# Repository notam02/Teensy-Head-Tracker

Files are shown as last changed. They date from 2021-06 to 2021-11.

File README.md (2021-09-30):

# Teensy Head Tracker
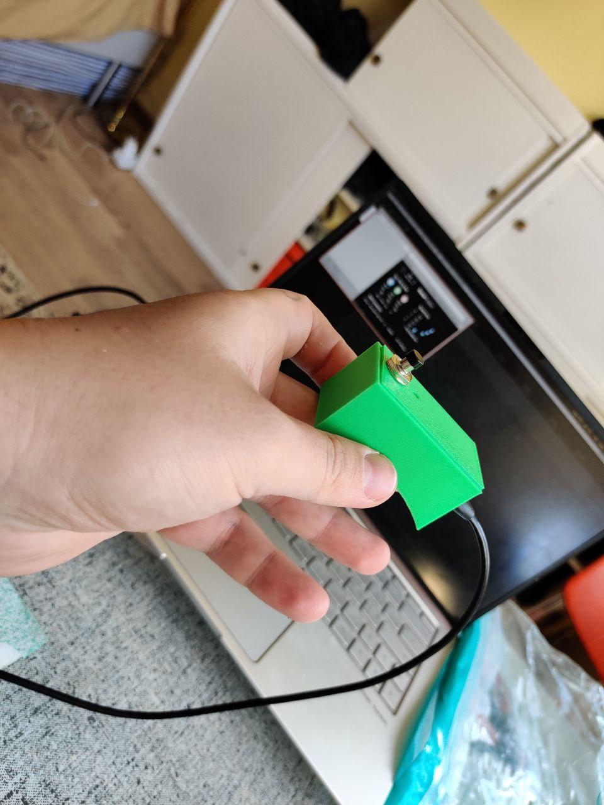
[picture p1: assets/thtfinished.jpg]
prototype1


Teensy Head Tracker is a fork of IEM's [Mr Head Tracker](https://git.iem.at/DIY/MrHeadTracker). The main change is switching the hardware setup to use a Teensy to simplify things. The head tracker transmits the data as 14 bit midi and no middle ware is necessary to use it.

Teensy Head Tracker's main use case is the compensation of the user's head movement during
binaural synthesis of a 3D audio scene. Therefore, the device is mounted on
the user's headphones and provides rotation data with opposite direction.
The audio scene gets rotated using this data.

Alternatively, with the original, non-inverse rotation data the device can
be used as a controller/pointing-device for employment in live-performances
or automation-writing for 3D audio productions. Another thinkable application
is the tracking of a 3D microphone's orientation during recording for a a
posteriori stabilization of the recorded scene.

The device is designed to act as a class-compliant USB-MIDI device,
providing plug-and-play compatibility on Windows, macOS and Linux.
With the usage of 14-bit MIDI, the rotation data is provided with a resolution
high enough to be not noticeable.

The idea is to make 3D audio production tools more assessable for everyone
and allow the user to perceive a more realistic binaural playback without the
need of third party software or expensive hardware (e.g. optical tracking
system) and - above all - without the need of an expensive multichannel
audio playback system.

## Hardware

- Teensy LC (cheaper, just as good) or Teensy 3.2
- [Adafruit BNO055 sensor](https://www.adafruit.com/product/2472) ( [Mouser link](https://no.mouser.com/ProductDetail/Adafruit/2472?qs=N%2F3wi2MvZWDmk8dteqdybw%3D%3D) ) or [this board, cheaper and just as good](https://www.adafruit.com/product/4646)

## Connections

### BNO055 sensor
BNO055 	<-> 	TEENSY 

VIN 	<-> 	3.3V

GND 	<-> 	GND

SDA 	<-> 	18

SCL 	<-> 	19

### Button
BUTTON 	<-> 	TEENSY

PIN A 	<-> 	3

PIN B 	<-> 	GND

## Enclosure

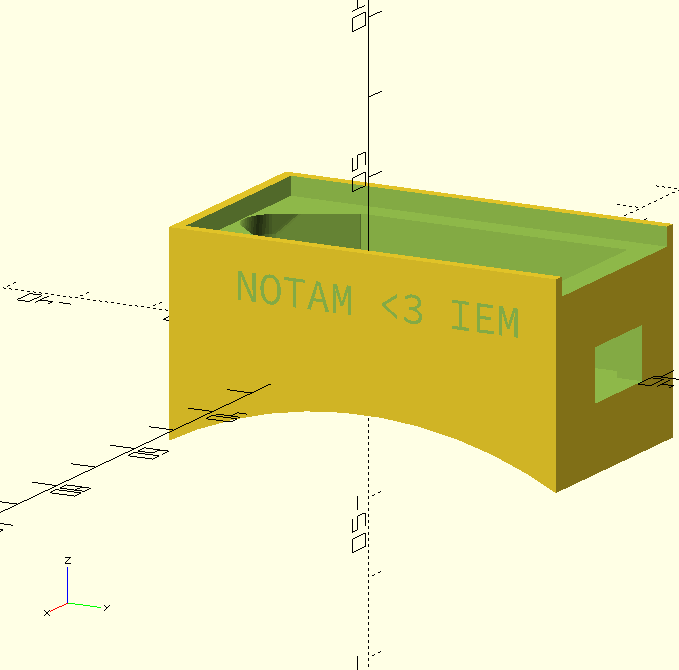
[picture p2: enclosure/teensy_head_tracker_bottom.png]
enclosure


This repository contains a 3D printable enclosure that fits on to a pair of headphones. There are stl-files you can import into your 3D printer slicer of choice and openscad files if you want to change the models or mess around with them.

## Software requirements:
- Platformio
- Teensyduino

## Uploading to the Teensy

With Platformio installed, download this repository and move into it using a terminal. Then run:
```
platformio run -t upload
```

## Calibration process

When first put into operation, the MrHeadTracker won't start sending rotation data until a full calibration was performed.
To do so:

1. look into your desired front direction
2. press and hold the push button for longer than 1s
3. release
4. nod/tilt your head forwards
5. press the button again while looking downward.

The calibration data is saved into the EEPROM memory and has to be done only when the mounting position has changed. 

## Changing front orientation
For changing the desired front orientation just press and release the push button shortly (below 1s). 

This is useful if the sensor starts drifting.

## Using it in SuperCollider

[The TeensyHeadTracker.quark SuperCollider package contains a plug-and-play style interface](https://github.com/notam02/TeensyHeadTracker.quark), otherwise see [examples/iem-headrotator.scd](examples/iem-headrotator.scd).

## Using it in Reaper
Usage in REAPER:
1. Add the "IEM SceneRotator" to an ambisonics track (before the decoder)
2. Open up the SceneRotator plugin
3. At the bottom of the panel, click the device drop down and choose "Teensy Head Tracker"
4. In the scheme, choose the scheme corresponding to the mode of the head tracker. By default it is Yaw Pitch Roll Direct. If you haven't changed it, choose "Mr HT YPR Direct"

## Changes from Mr Head Tracker

- Use Teensy (and Teensy's EEPROM and MIDI libs) instead of Arduino
- Converted to platformio project
- Use Bounce for debouncing
- Various small changes to the code
- Create 3D printable enclosure

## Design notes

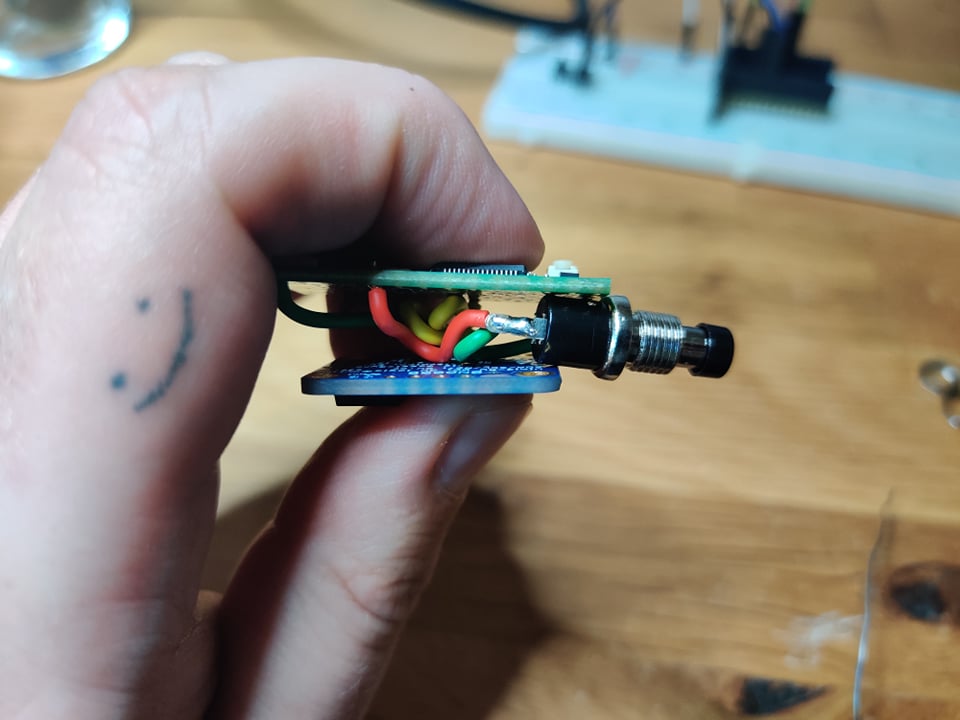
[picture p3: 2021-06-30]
assets/teensy-head-proto2.jpg

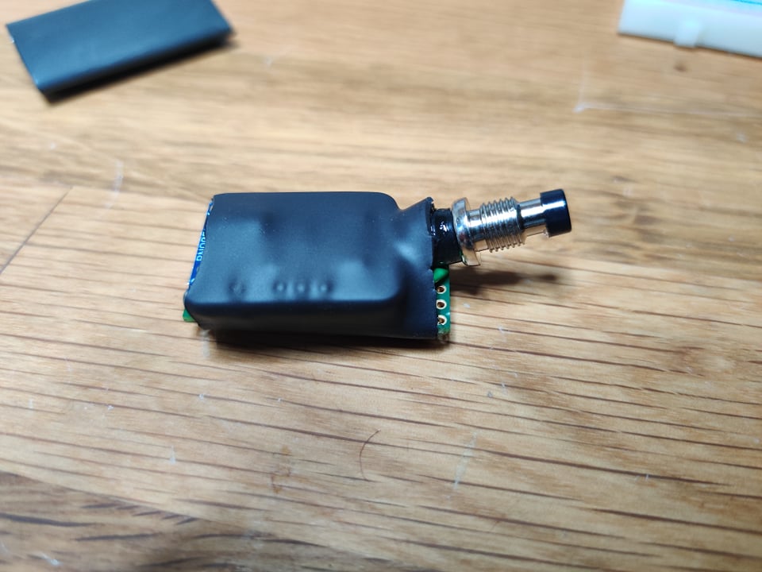
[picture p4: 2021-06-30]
assets/teensy-head-proto1.jpg

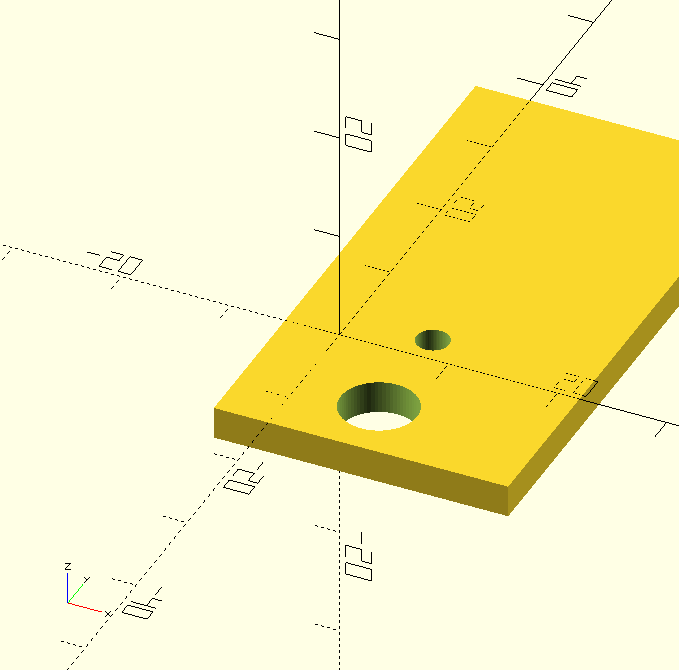
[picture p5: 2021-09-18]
enclosure/teensy_head_tracker_top.png

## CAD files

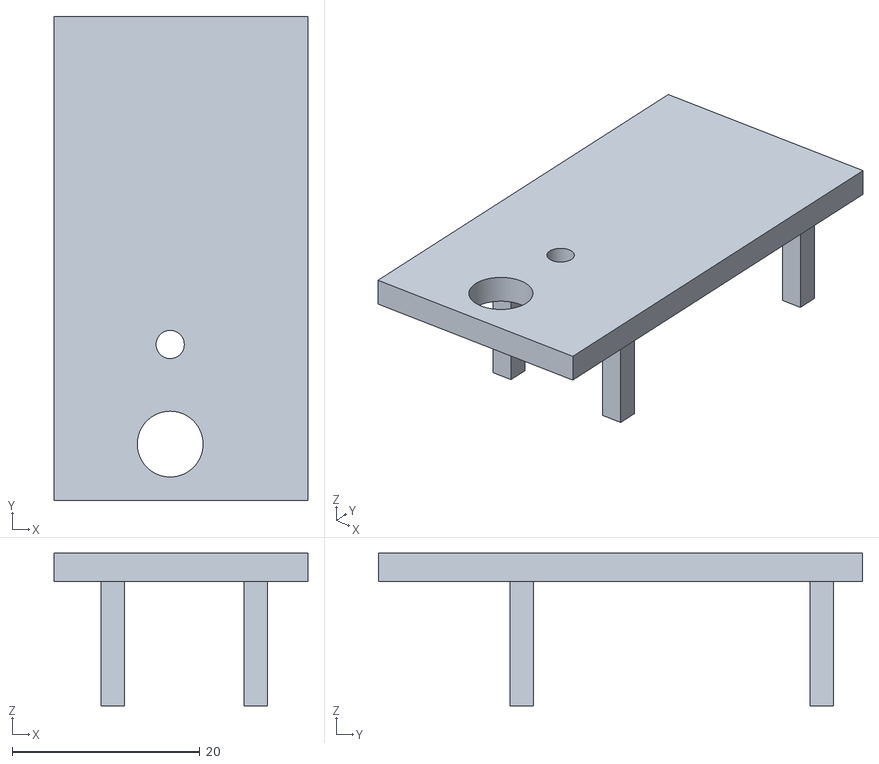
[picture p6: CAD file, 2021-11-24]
enclosure/teensy_head_tracker_top.stl
27.0 x 51.5 x 16.2

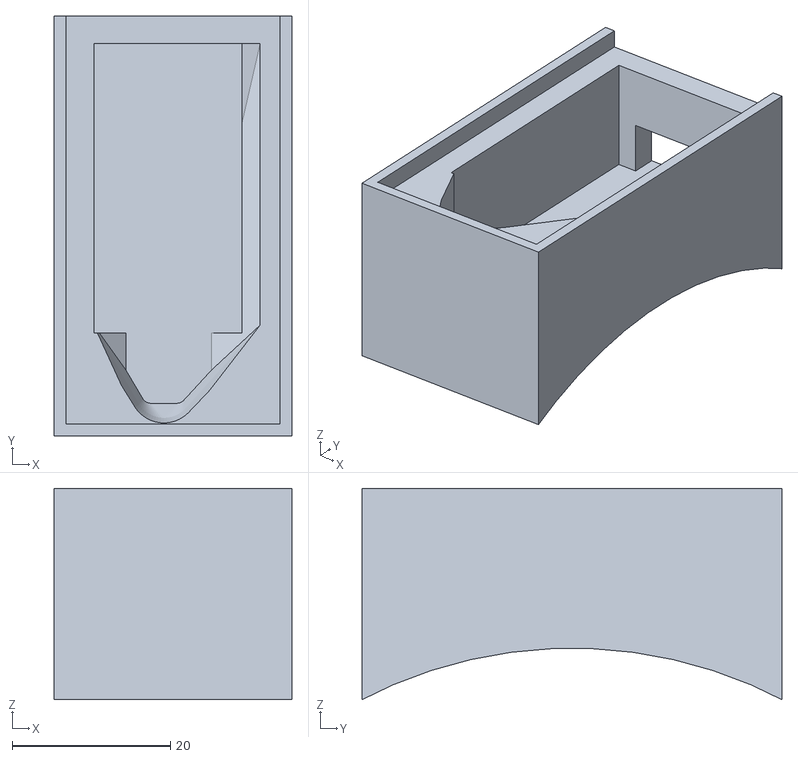
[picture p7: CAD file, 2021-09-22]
enclosure/teensy_head_tracker_bottom.stl
30.0 x 53.0 x 26.7

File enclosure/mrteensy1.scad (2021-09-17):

include </home/mads/code/scadlib/teensy32.scad>
include </home/mads/code/scadlib/pushbutton1.scad>
$fn=70;

module adabno055(){
	/* PCB */
	pcbw=21;
	pcbthick=1.6;
	pcblen=27;

	// PCB inputs. Probably not entirely precise
	for (i = [0:4]) {
		pinDia=1.9;
		pinSpacing=1.25;
		offsetFromEdge=6.16;
		color("red") translate([pinDia,offsetFromEdge+(i*(pinSpacing+pinDia)),pcbthick])circle(d=pinDia);
	}

	color("blue") cube([pcbw, pcblen, pcbthick]);
}

spaceBetweenTwoBoards=18;
electronicsHeight=teensy32Thickness()*2+spaceBetweenTwoBoards;

module headtrackerElectronics(){
	rotate([0,0,90]) translate([-6,-teensy32Width()/2,8]) pushbutton1();
	translate([0,8,spaceBetweenTwoBoards]) adabno055();
	teensy32(0,0);
}

outerWidth=30;
outerLen=53;
bnoWidth=21;

module pushB(){
		rotate([0,0,90]) translate([-8,-teensy32Width()/2,8]) pushbutton1();
}
module bottom(){
	union(){
		// BOTTOM
		difference(){
			difference(){
				// The main / outer shape
				color("lightcyan") translate([-5,-14,-2]) cube([outerWidth,outerLen, electronicsHeight]);

				// The inner shape
				hull(){
					color("orangered") cube([max(bnoWidth, teensy32Width()),teensy32Len(), electronicsHeight]);
					pushB();

				}

				textCarve();
				translate([1.5,1.5,electronicsHeight-(lidHeight/2.0)])top();
				/* teensy32(padding=2, extraUsbLen=30); */
			}

			teensy32USBPlug(3,20);
		}

		// Bow
		translate([-5,-14,-electronicsHeight])
			difference(){
				cube([outerWidth,outerLen, electronicsHeight]);
				bowDia=110;
				rotate([90,0,90])translate([outerLen/2,-40,-8])cylinder(h=outerWidth*2,d=bowDia,center=false);
			}
	}
}

module textCarve(){
	textDepth=1;
	textSize=4;
	thisfont="SourceCodePro";
	rotate([90,0,90])
		translate([-5,electronicsHeight/2.0,outerWidth-textSize-textDepth])
			linear_extrude(textDepth) text("NOTAM <3 IEM", textSize, thisfont);
}

// TOP
lidHeight=3;
module top(){
	 subtractWidth=3;

	 translate([0,0,-lidHeight])
	 difference(){
		color("thistle")
			translate([-5,-14,0])
			cube([outerWidth-subtractWidth,outerLen, lidHeight]);

		// Cutout for reset button
		rotate([0,0,90])
			translate([2.6,-teensy32Width()/2 + (subtractWidth/2),-lidHeight/2])
			cylinder(h=lidHeight*2,d=3,center=false);

		// Cutout for main button
		rotate([0,0,90])
			translate([-8,-teensy32Width()/2+ (subtractWidth/2),-lidHeight/2])
			cylinder(h=lidHeight*2,d=6.75,center=false);
	}
}

bottom();

translate([50,0,0]) top();

//#headtrackerElectronics();

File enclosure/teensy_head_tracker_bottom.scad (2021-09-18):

include <teensy_head_tracker_main.scad>

bottom();

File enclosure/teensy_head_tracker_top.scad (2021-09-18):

include <teensy_head_tracker_main.scad>

top();

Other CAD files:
enclosure/teensy_head_tracker_main.scad

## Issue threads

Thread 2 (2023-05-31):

Error when compiling (BNO085)

gzalles, 2023-05-31:
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

madskjeldgaard, 2023-06-01:
Hey @gzalles did you setup the device as described here: https://github.com/notam02/Teensy-Head-Tracker#using-it-in-reaper

Hope you get it sorted <3

gzalles, 2023-06-01:
I only had to do the first step from above and restart Reaper. Now it works
Amazing! <3

madskjeldgaard, 2023-06-01:
Great to hear. Have fun ❤️Sent from my iPhoneOn 1 Jun 2023, at 21.47, Gabriel Zalles Ballivian ***@***.***> wrote:
I only had to do the first step from above and restart Reaper. Now it works
Amazing! <3

—Reply to this email directly, view it on GitHub, or unsubscribe.You are receiving this because you commented.Message ID: ***@***.***>

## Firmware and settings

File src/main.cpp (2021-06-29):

/*
    MrHeadTracker Switchable based on the BNO055 sensor
    Copyright (C) 2016-2017  Michael Romanov, Daniel Rudrich

  CHANGELOG
      2017-06-20: - initial release

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
    You should have received a copy of the GNU General Public License
    along with this program.  If not, see <http://www.gnu.org/licenses/>.
*/

#include <Adafruit_BNO055.h>
#include <Adafruit_Sensor.h>
#include <Arduino.h>
#include <Bounce.h>
#include <EEPROM.h>

// BNO055 Instance
Adafruit_BNO055 bno = Adafruit_BNO055();

#define DEBUG false

// Pins and Settings
#define LED 13
#define button 3
#define invSwitch 4
#define quatSwitch 5
#define pi 3.1415926536
#define radTo14 2607.594587617613379
#define oneTo14 8191
#define qCalAddr 0 // EEPROM qCal address
#define debounceDelay 50

// Disable / enable the quaternion switch and inv switch, otherwise values are
// hard coded
constexpr bool quatSwitchActive = false;
constexpr bool invSwitchActive = false;

constexpr bool invertQuaternion = true;
enum MidiSendMode { Quaternion, YawPitchRoll };
auto midiMode = MidiSendMode::YawPitchRoll;

// --------------------------------------------
volatile unsigned long lastChangeTime, lastPressTime, lastReleaseTime = 0;
volatile bool buttonState = 1;
volatile bool newButtonState = 0;
int action = 0;
int calibrationState = 0;

Bounce mainButton(button, debounceDelay);

uint16_t lastW = 63;
uint16_t newW = 63;
uint16_t lastX = 63;
uint16_t newX = 63;
uint16_t lastY = 63;
uint16_t newY = 63;
uint16_t lastZ = 63;
uint16_t newZ = 63;


// Quaternions and Vectors
imu::Quaternion qCal, qCalLeft, qCalRight, qIdleConj = {1, 0, 0, 0};
imu::Quaternion qGravIdle, qGravCal, quat, steering, qRaw;

imu::Vector<3> gRaw; //
const imu::Vector<3> refVector = {1, 0, 0};
imu::Vector<3> vGravIdle, vGravCal;
imu::Vector<3> ypr; // yaw pitch and roll angles

imu::Vector<3> getGravity();

void blink(int delayTime, size_t numBlinks = 4) {
  for (size_t blink_num = 0; blink_num < numBlinks; blink_num++) {
    digitalWrite(LED, HIGH);
    delay(delayTime / 2);
    digitalWrite(LED, LOW);
    delay(delayTime / 2);
  }
}

void buttonChange() {
  lastChangeTime = millis();
  mainButton.update();
  buttonState = mainButton.read();
  /* buttonState = digitalRead(button); */
  newButtonState = 1;
}

void resetOrientation() {
  qCalLeft = qCal.conjugate();
  qCalRight = qCal;
}

imu::Vector<3> getGravity() {
  imu::Vector<3> gravity = bno.getVector(Adafruit_BNO055::VECTOR_GRAVITY);
  gravity = gravity.scale(-1);
  gravity.normalize();
  return gravity;
}

void calibrate() {
  imu::Vector<3> g, gCal, x, y, z;
  // g = refVector.getRotated(&qGravIdle); //g =
  // qGravIdle.rotateVector(refVector);
  g = vGravIdle;
  z = g.scale(-1);
  z.normalize();

  // gCal = refVector.getRotated(&qGravCal); //gCal =
  // qGravCal.rotateVector(refVector);
  gCal = vGravCal;
  y = gCal.cross(g);
  y.normalize();

  x = y.cross(z);
  x.normalize();

  imu::Matrix<3> rot;
  rot.cell(0, 0) = x.x();
  rot.cell(1, 0) = x.y();
  rot.cell(2, 0) = x.z();
  rot.cell(0, 1) = y.x();
  rot.cell(1, 1) = y.y();
  rot.cell(2, 1) = y.z();
  rot.cell(0, 2) = z.x();
  rot.cell(1, 2) = z.y();
  rot.cell(2, 2) = z.z();

  qCal.fromMatrix(rot);
  EEPROM.put(qCalAddr, qCal);

  resetOrientation();

  if (DEBUG)
    Serial.println("done calibrating");
}

// ================================================================
// ===                      INITIAL SETUP                       ===
// ================================================================

void setup() {
  if (DEBUG) {
    while (!Serial)
      ;
  }

  if (!bno.begin(bno.OPERATION_MODE_IMUPLUS)) {
    /* There was a problem detecting the BNO055 ... check your connections */
    Serial.print(
        "Ooops, no BNO055 detected ... Check your wiring or I2C ADDR!");
    while (1)
      ;
  }

  pinMode(button, INPUT_PULLUP);
  if (invSwitchActive) {
    pinMode(invSwitch, INPUT_PULLUP);
  }

  if (quatSwitchActive) {
    pinMode(quatSwitch, INPUT_PULLUP);
  }

  attachInterrupt(digitalPinToInterrupt(button), buttonChange, CHANGE);

  pinMode(LED, OUTPUT);
  digitalWrite(LED, LOW);
  EEPROM.get(qCalAddr, qCal); // read qCal from EEPROM and print values
  resetOrientation();

  bno.setExtCrystalUse(true);
  delay(1000);
}

// ================================================================
// ===                    MAIN PROGRAM LOOP                     ===
// ================================================================

void loop() {
  // ============== BUTTON CHECK ROUTINE ==========================
  action = 0; // do nothing, just chill... for now!

  if (newButtonState) {
    if (!buttonState) {
      // pressed
      if (DEBUG)
        Serial.println("Pressed");

      blink(25);

      lastPressTime = lastChangeTime;
      /* if (millis() - lastPressTime > 1000) { */
      /*   if (DEBUG) */
      /*     Serial.println("Long press"); */
      /*   action = 2;         // held longer than ^ ms */
      /*   newButtonState = 0; // only once! */
      /* } */
    }
    {
      // released
      newButtonState = 0;
      lastReleaseTime = lastChangeTime;
      action = 1; // short button click
      if (DEBUG)
        Serial.println("released");

      blink(10);

      if (lastReleaseTime - lastPressTime > 1000) {
        action = 2; // release after hold > ^ ms

        if (DEBUG)
          Serial.println("long press release");
      }
    }
  }

  // ============== QUATERNION DATA ROUTINE ======================

  imu::Quaternion qRaw = bno.getQuat(); // get sensor raw quaternion data

  steering = qIdleConj * qRaw; // calculate relative rotation data
  quat = qCalLeft * steering;  // transform it to calibrated coordinate system
  quat = quat * qCalRight;

  /* if (invSwitchActive && digitalRead(invSwitch) == LOW) { */
  /*   quat = quat.conjugate(); */
  /* } */
  if (invertQuaternion) {
    quat = quat.conjugate();
  }

  // ============== SEND MIDI ROUTINE ===========================

  if (quatSwitchActive) {
    midiMode = digitalRead(quatSwitch);
  };

  switch (midiMode) {
  case MidiSendMode::Quaternion: // send quaternion data
    newW = (uint16_t)(oneTo14 * (quat.w() + 1));
    newX = (uint16_t)(oneTo14 * (quat.x() + 1));
    newY = (uint16_t)(oneTo14 * (quat.y() + 1));
    newZ = (uint16_t)(oneTo14 * (quat.z() + 1));

    if (newW != lastW) {
      usbMIDI.sendControlChange(48, newW & 0x7F, 1);
      usbMIDI.sendControlChange(16, (newW >> 7) & 0x7F, 1);
    }
    if (newX != lastX) {
      usbMIDI.sendControlChange(49, newX & 0x7F, 1);
      usbMIDI.sendControlChange(17, (newX >> 7) & 0x7F, 1);
    }
    if (newY != lastY) {
      usbMIDI.sendControlChange(50, newY & 0x7F, 1);
      usbMIDI.sendControlChange(18, (newY >> 7) & 0x7F, 1);
    }
    if (newZ != lastZ) {
      usbMIDI.sendControlChange(51, newZ & 0x7F, 1);
      usbMIDI.sendControlChange(19, (newZ >> 7) & 0x7F, 1);
    }

    lastW = newW;
    lastX = newX;
    lastY = newY;
    lastZ = newZ;
    break;

  case MidiSendMode::YawPitchRoll:
    ypr = quat.toEuler();
    newZ = (uint16_t)(radTo14 * ((ypr[0] + pi)));
    newY = (uint16_t)(radTo14 * ((ypr[1] + pi)));
    newX = (uint16_t)(radTo14 * ((ypr[2] + pi)));

    if (newZ != lastZ) {
      usbMIDI.sendControlChange(48, newZ & 0x7F, 1);
      usbMIDI.sendControlChange(16, (newZ >> 7) & 0x7F, 1);
    }
    if (newY != lastY) {
      usbMIDI.sendControlChange(49, newY & 0x7F, 1);
      usbMIDI.sendControlChange(17, (newY >> 7) & 0x7F, 1);
    }
    if (newX != lastX) {
      usbMIDI.sendControlChange(50, newX & 0x7F, 1);
      usbMIDI.sendControlChange(18, (newX >> 7) & 0x7F, 1);
    }
    lastX = newX;
    lastY = newY;
    lastZ = newZ;
    break;
  };

  // ============== BUTTON ACTION ROUTINE ======================
  switch (action) {
  case 1: // short button click
    if (calibrationState == 1) {
      vGravCal = getGravity();
      calibrate();
      calibrationState = 0;

    } else {
      qIdleConj = qRaw.conjugate();
    }
    break;
  case 2: // long hold
    if (!calibrationState) {
      calibrationState = 1;
      qIdleConj = qRaw.conjugate();
      vGravIdle = getGravity();
    }
  }
}

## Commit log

2021-06-29 Make inversion and quaternion switches optional
2021-06-30 teensy 3.2
2021-09-16 Add teensy 3.2 model
    [mrteensy1.scad, teensy32.stl]
2021-09-17 All electronics
    [mrteensy1.scad]
2021-09-17 finish v1
    [mrteensy1.scad, mrteensy1.stl, teensy32.stl]
2021-09-17 Add bow
    [mrteensy1.scad]
2021-09-17 embed lid in bottom
    [mrteensy1.scad]
2021-09-17 add stl for new enclosure
    [mrteensy1.stl]
2021-09-18 Seperate top and bottom and make mounting hole for button larger
    [mrteensy1.stl, teensy_head_tracker_bottom.scad, teensy_head_tracker_bottom.stl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]
2021-09-18 Adjust lid length to fit cutout;
    [teensy_head_tracker_main.scad]
2021-09-18 Increase bow size
    [teensy_head_tracker_main.scad]
2021-09-18 Smarter height based on pushbutton height
    [teensy_head_tracker_main.scad]
2021-09-18 enclosure v2: cutout to stabilize teensy, bigger usb hole and wider bow
    [teensy_head_tracker_bottom.stl, teensy_head_tracker_main.scad, teensy_head_tracker_top.stl]
2021-09-22 Add padding around teensy to make it fit better
    [teensy_head_tracker_main.scad]
2021-09-22 More room for the button
    [teensy_head_tracker_main.scad]
2021-11-24 fix(Enclosure): Update enclosure top to contain legs that keep the Teensy down
    [teensy_head_tracker_main.scad, teensy_head_tracker_top.stl]

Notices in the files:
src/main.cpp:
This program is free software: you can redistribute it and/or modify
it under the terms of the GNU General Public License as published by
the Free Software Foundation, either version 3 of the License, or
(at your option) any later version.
